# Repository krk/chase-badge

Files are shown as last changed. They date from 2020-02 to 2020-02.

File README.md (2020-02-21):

# chase-badge

Designed using [KiCad](https://kicad-pcb.org/).

I tried to follow datasheet recommendations and tried to base the design on application note schematics and PCB layouts of the active components.

First revision of the board in the repo is rev-8. Earlier revisions are not available in this repo.

Schematics contain notes and all components should have their datasheet in their details in KiCAD.

### Kudos

- to [@smcatala](https://github.com/smcatala) for reviewing the designs!

### Connectors

1. USB-C for power, charging and with bootloader programming.
2. FPC 4-pin for add-on boards.
3. Li-Po JST-SH 2-pin.

### Used ICs

##### ATTINY85V-20SU

- Chosen over ATTINY85V-10SU so we may support [bit-banged USB protocol](https://www.obdev.at/products/vusb/index.html) for programming the badge only with a USB cable. [datasheet](http://ww1.microchip.com/downloads/en/DeviceDoc/atmel-2586-avr-8-bit-microcontroller-attiny25-attiny45-attiny85_datasheet.pdf).

##### TLC6C9512PWR shift register

Chosen for low power consumption and low parts count. [datasheet](http://www.ti.com/lit/ds/symlink/tlc6c5912.pdf).

#### TPS63000 buck-boost regulator

[datasheet](http://www.ti.com/lit/ds/symlink/tps63000.pdf)

#### MCP73837-FCI_UN battery charge manager

[datasheet](http://ww1.microchip.com/downloads/en/DeviceDoc/20002071C.pdf)

### Tested

- Programming ATtiny85 with [Tiny AVR Programmer](https://www.sparkfun.com/products/11801)
- ATtiny85, TLC6C9512 and LEDs can work as expected when powered externally
- 3.3V or 5V is supported.

### Untested

- Power regulator
- Battery charge manager
- XSIG1 external signal, for supporting a buzzer, microphone etc.
- USB bootloader and programming from USB cable.

### TODO

1. Test everything under "untested" above.
2. Determine Li-Po battery size.

### PCB renders of rev-8

Note that some footprints are missing from the renders.

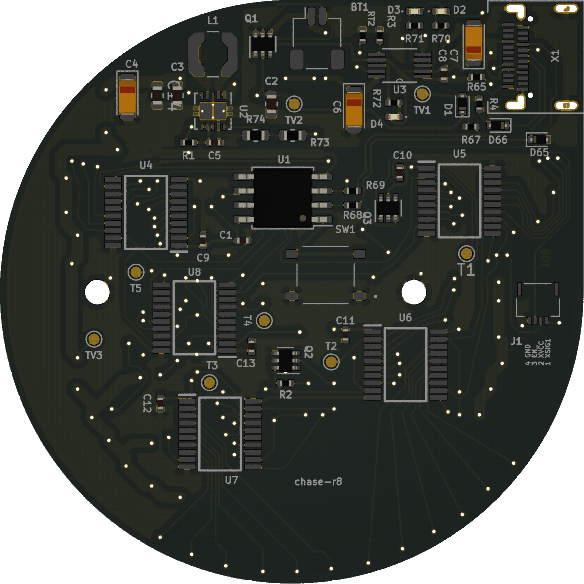
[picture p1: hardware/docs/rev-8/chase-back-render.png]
back


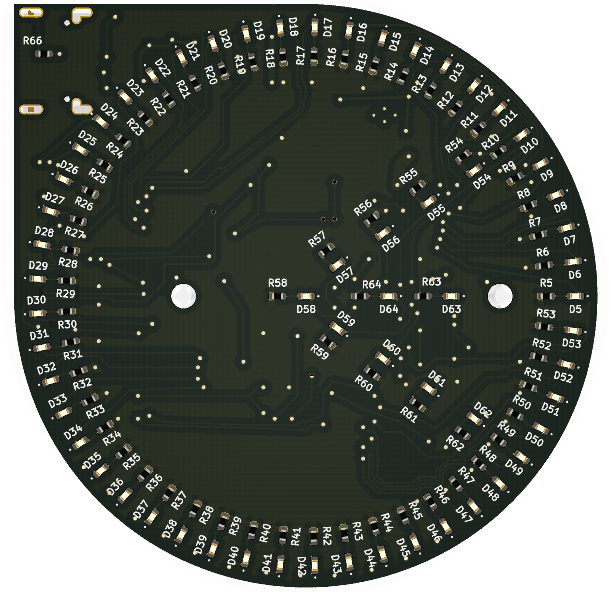
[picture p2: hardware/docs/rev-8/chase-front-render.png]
front


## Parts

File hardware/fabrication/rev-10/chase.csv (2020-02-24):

Part/Designator | Manufacture Part Number/Seeed SKU | Quantity
R1 | 0402WGF1000TCE | 1
R3 | 0402WGF1001TCE | 1
R4 | 0402WGF1003TCE | 1
R2,R5,R6,R7,R8,R9,R10,R11,R12,R13,R14,R15,R16,R17,R18,R19,R20,R21,R22,R23,R24,R25,R26,R27,R28,R29,R30,R31,R32,R33,R34,R35,R36,R37,R38,R39,R40,R41,R42,R43,R44,R45,R46,R47,R48,R49,R50,R51,R52,R53,R54,R55,R56,R57,R58,R59,R60,R61,R62,R63,R64,R70,R71,R72 | 0402WGF4300TCE | 64
R65,R66 | 0402WGF5101TCE | 2
R68,R69 | 0402WGF715JTCE | 2
X1 | 12401610E4#2A | 1
U1 | ATTINY85V-20SU | 1
C1,C5,C8,C9,C10,C11,C12,C13 | CL05B104KO5NNNC | 8
Q1 | DMC3400SDW-7 | 1
Q2,Q3 | DMN61D9UDW | 2
D2,D3,D4,D5,D6,D7,D8,D9,D10,D11,D12,D13,D14,D15,D16,D17,D18,D19,D20,D21,D22,D23,D24,D25,D26,D27,D28,D29,D30,D31,D32,D33,D34,D35,D36,D37,D38,D39,D40,D41,D42,D43,D44,D45,D46,D47,D48,D49,D50,D51,D52,D53,D54,D55,D56,D57,D58,D59,D60,D61,D62,D63,D64 | FC-F1005HOK-600H5 | 63
J1 | FH12-6S-0.5SH(55) | 1
C2,C3,C14 | GRM188Z71A106MA73D | 3
D65,D66 | LM5Z3V6T1G | 2
L1 | LPS4018-222MR_ | 1
U3 | MCP73837-FCI_UN | 1
D1 | NSVR0320MW2T1G | 1
RT2 | NTCG103JF103FT1 | 1
BT1 | SM02B-SRSS-TB(LF)(SN) | 1
R67 | TC0225F1501TCE | 1
C4,C6,C7 | TC212A476K010Y | 3
U4,U5,U6,U7,U8 | TLC6C5912GQPWRQ1 | 5
U2 | TPS63000DRCR | 1
SW1 | TS-1187A-B-A-B | 1

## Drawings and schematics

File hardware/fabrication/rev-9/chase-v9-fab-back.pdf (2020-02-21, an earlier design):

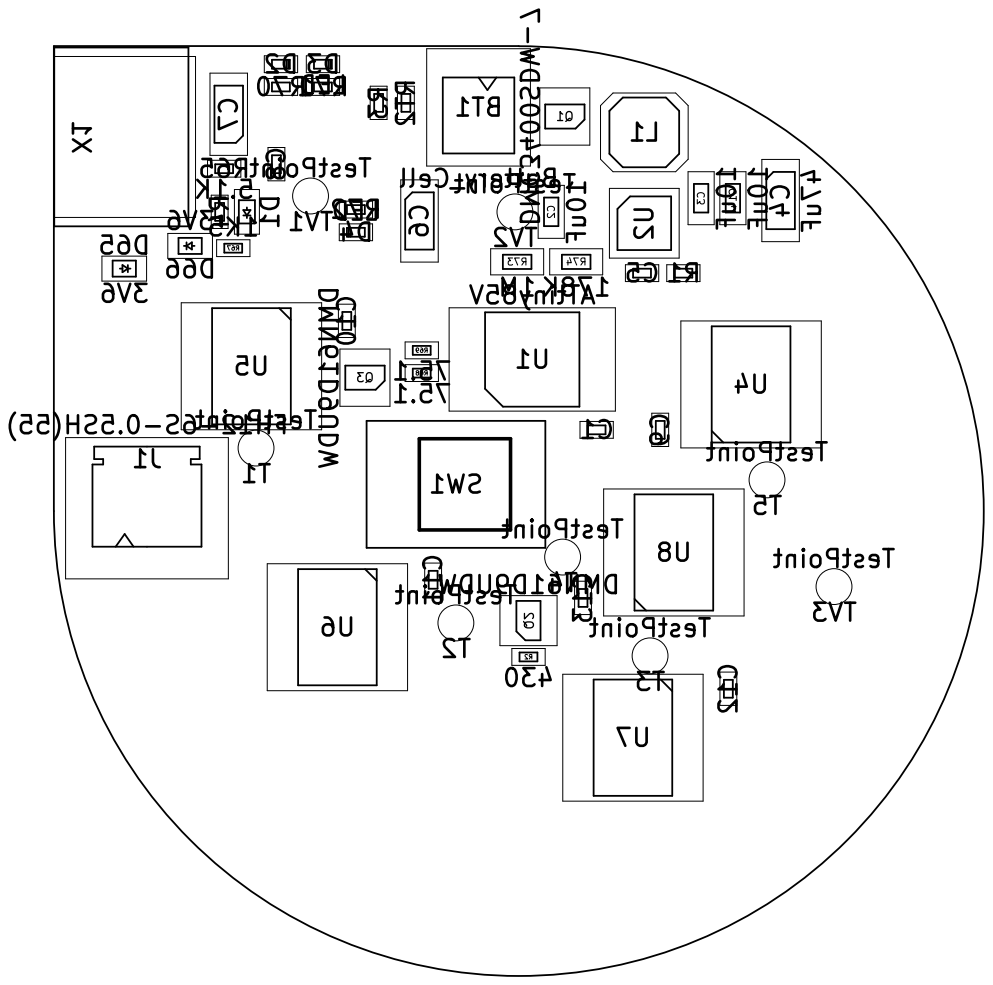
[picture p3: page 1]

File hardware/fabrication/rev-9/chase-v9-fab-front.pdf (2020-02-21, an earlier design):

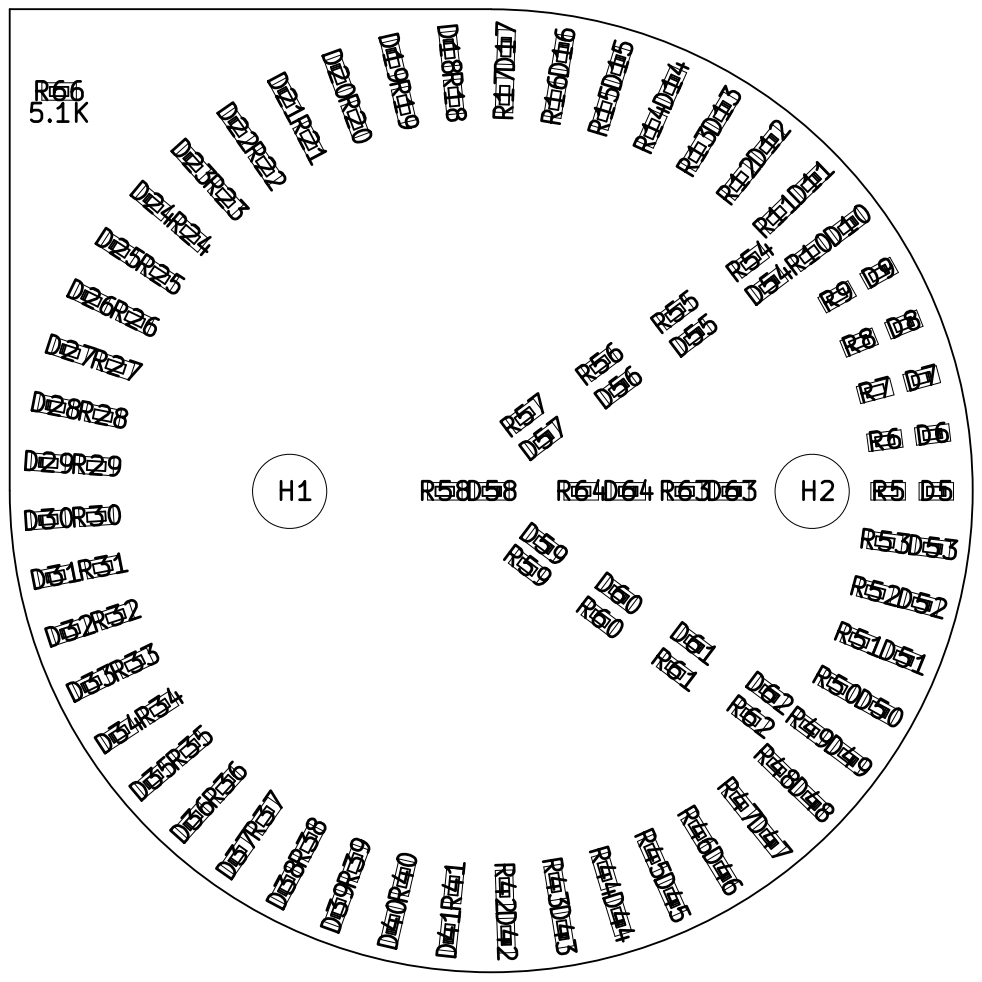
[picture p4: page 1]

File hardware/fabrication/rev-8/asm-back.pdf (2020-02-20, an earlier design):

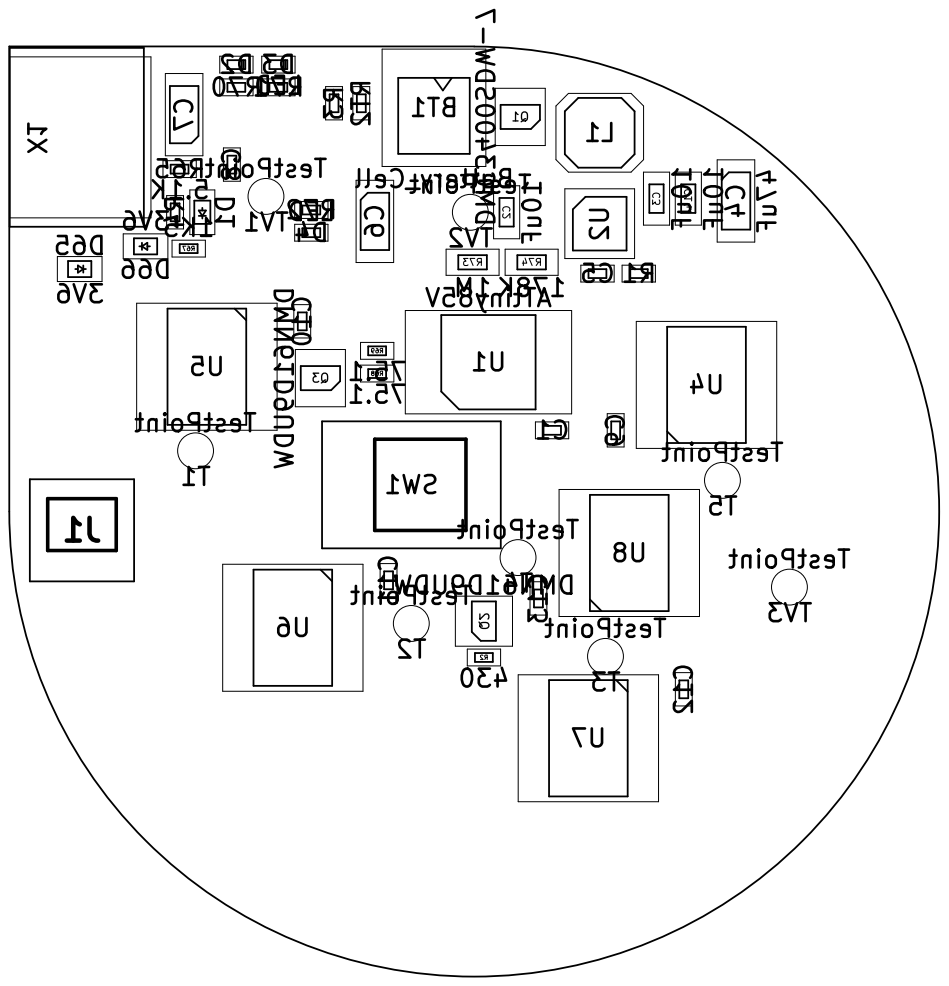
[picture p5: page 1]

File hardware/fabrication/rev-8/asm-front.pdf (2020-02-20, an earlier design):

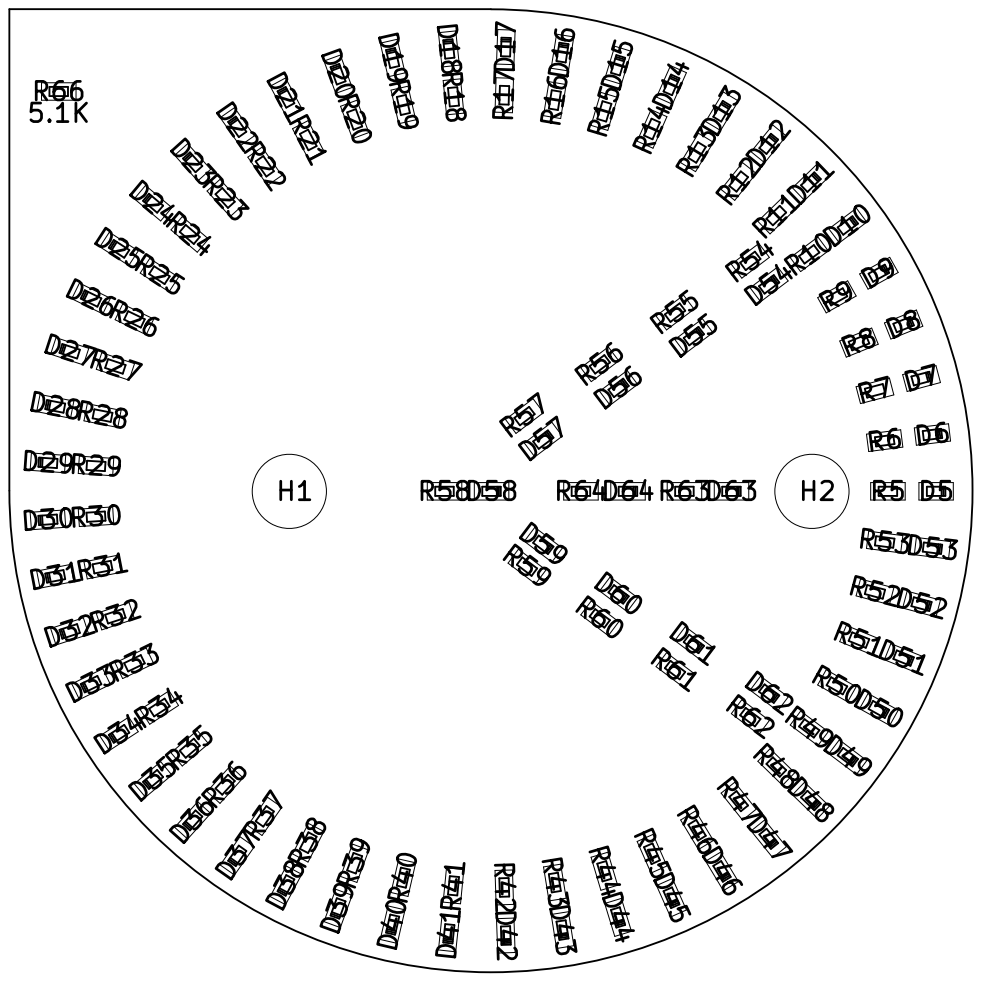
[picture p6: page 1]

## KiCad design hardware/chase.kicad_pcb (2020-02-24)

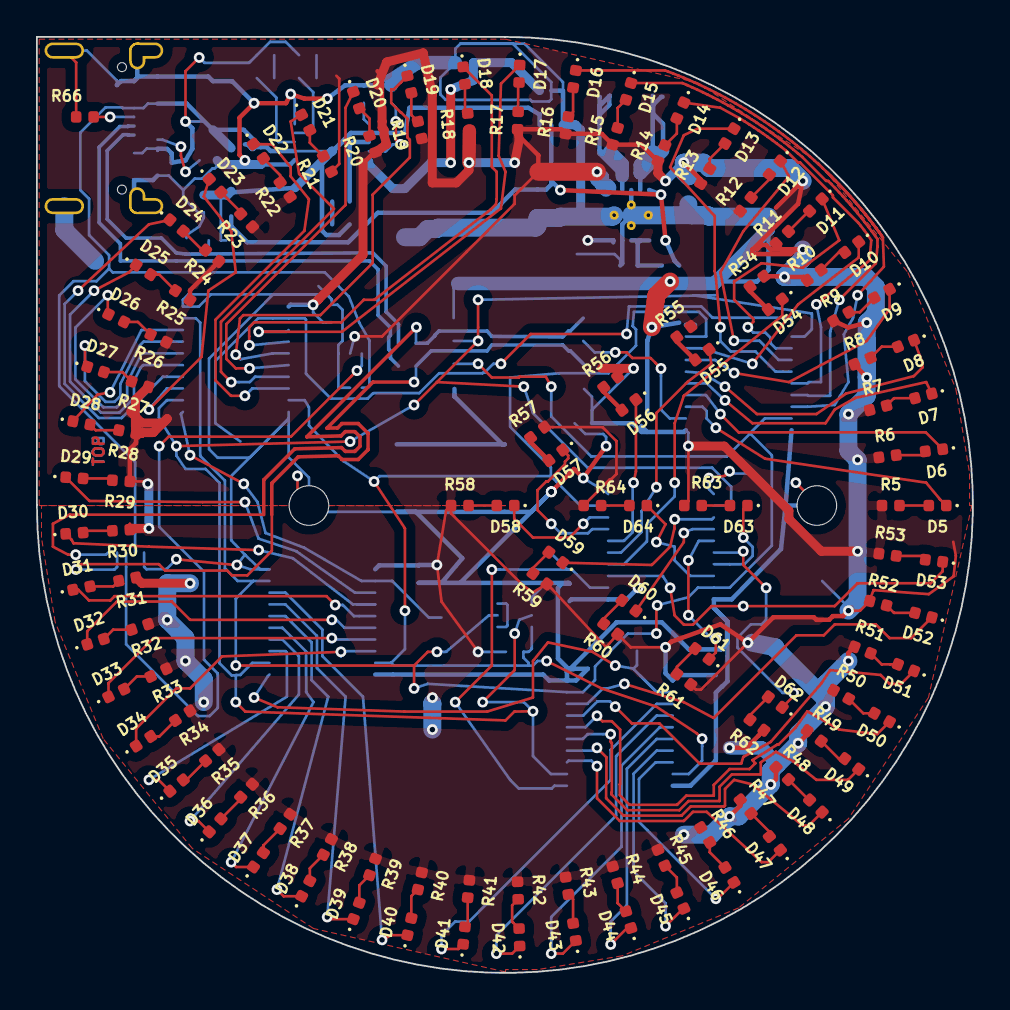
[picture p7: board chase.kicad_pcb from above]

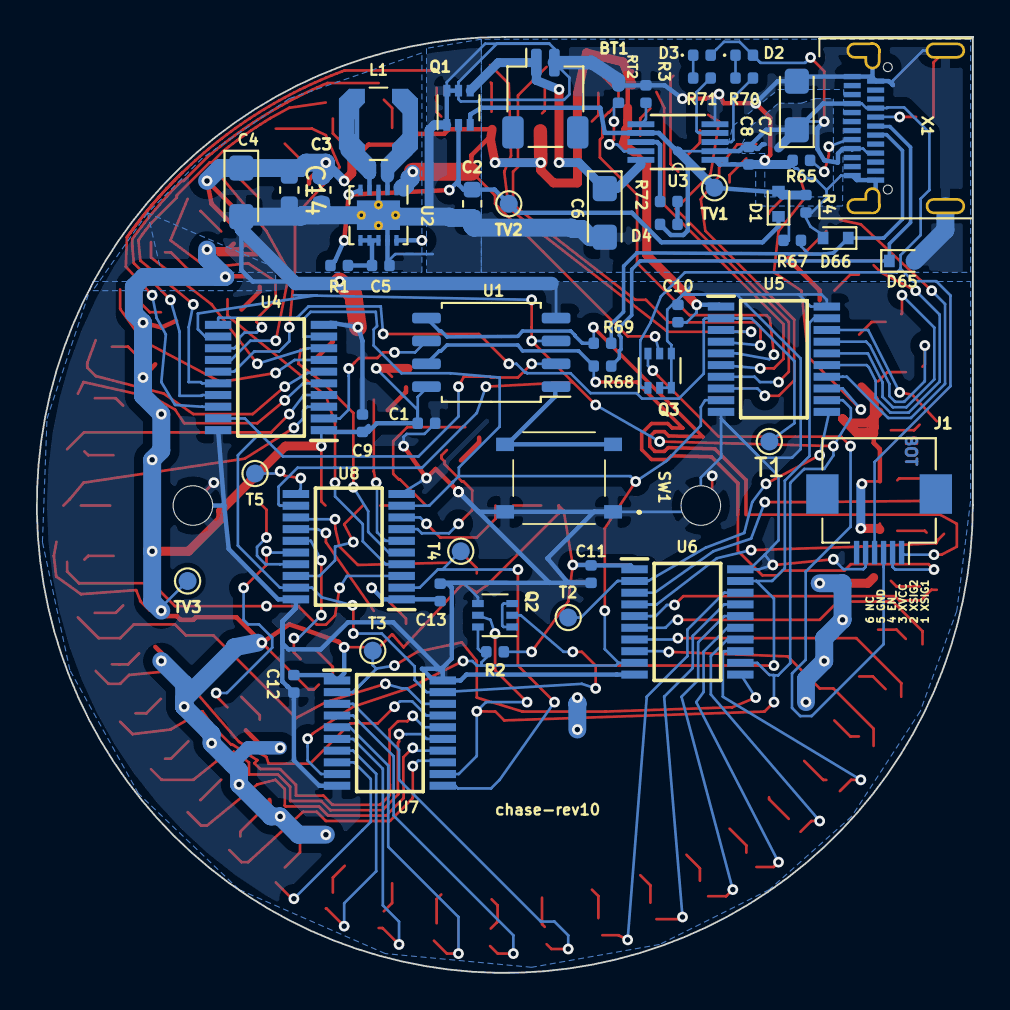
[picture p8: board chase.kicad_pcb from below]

Board: 2 copper layers, 52.0 x 52.0 mm, 179 parts (56 on the bottom side), 154 nets.

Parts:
BT1: Battery_Cell; JST_SH_SM02B-SRSS-TB_1x02-1MP_P1.00mm_Horizontal
C1, C5, C8, C9, C10, C11, C12, C13: 100n; C_0402_1005Metric
C2, C3, C14: 10uF; C_0603_1608Metric
C4, C6, C7: 47uF; CP_EIA-3216-18_Kemet-A
D1: D; D_SOD-523
D2, D3, D4, D5, D6, D7, D8, D9, D10, D11, D12, D13, D14, D15, D16, D17, D18, D19, D20, D21, D22, D23, D24, D25, D26, D27, D28, D29, D30, D31, D32, D33, D34, D35, D36, D37, D38, D39, D40, D41, D42, D43, D44, D45, D46, D47, D48, D49, D50, D51, D52, D53, D54, D55, D56, D57, D58, D59, D60, D61, D62, D63, D64: LED; LED_0402_1005Metric
D65, D66: 3V6; D_SOD-523
H1, H2: MountingHole_Pad; MountingHole_2.2mm_M2_ISO7380
J1: FH12-6S-0.5SH(55); Hirose_FH12-6S-0.5SH_1x06-1MP_P0.50mm_Horizontal
L1: 2.2uH; L_Coilcraft_LPS4018
Q1: DMC3400SDW-7; SOT-363_SC-70-6
Q2, Q3: DMN61D9UDW; SOT-363_SC-70-6
R1: 100; R_0402_1005Metric
R2, R5, R6, R7, R8, R9, R10, R11, R12, R13, R14, R15, R16, R17, R18, R19, R20, R21, R22, R23, R24, R25, R26, R27, R28, R29, R30, R31, R32, R33, R34, R35, R36, R37, R38, R39, R40, R41, R42, R43, R44, R45, R46, R47, R48, R49, R50, R51, R52, R53, R54, R55, R56, R57, R58, R59, R60, R61, R62, R63, R64, R70, R71, R72: 430; R_0402_1005Metric
R3: 1K; R_0402_1005Metric
R4: 100K; R_0402_1005Metric
R65, R66: 5.1K; R_0402_1005Metric
R67: 1K5; R_0402_1005Metric
R68, R69: 75.1; R_0402_1005Metric
RT2: 10K; R_0402_1005Metric
SW1: TS-1187A-B-A-B; TS1187ABAB
T1, T2, T3, T4, T5: TestPoint; TestPoint_Pad_D1.0mm
TV1, TV2, TV3: TestPoint; TestPoint_Pad_D1.0mm
U1: ATtiny85V; SOIC-8_5.275x5.275mm_P1.27mm
U2: TPS63000; Texas_DRC0010J_ThermalVias
U3: MCP73837-FCI_UN; SOP50P490X110-8N
U4, U5, U6, U7, U8: TLC6C5912GQPWRQ1; SOP65P640X120-20N
X1: USB3.1_TYPEC; Type-C_3.1_24P

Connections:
/LED Driver 1/RCK: Q2.5, U1.3, U4.12, U5.12, U6.12, U7.12, U8.12
/LED Driver 1/SER_IN: U1.6, U4.2
/LED Driver 1/SRCK: Q2.2, U1.2, U4.19, U5.19, U6.19, U7.19, U8.19
/LED Driver 1/~CLR: Q2.6, R2.1, U4.9, U5.9, U6.9, U7.9, U8.9
/LED Driver 2/SER_IN: T1.1, U4.11, U5.2
/LED Driver 3/SER_IN: T2.1, U5.11, U6.2
/LED Driver 4/SER_IN: T3.1, U6.11, U7.2
/LED Driver 5/SER_IN: T4.1, U7.11, U8.2
/LED Driver 5/SER_OUT: T5.1, U8.11
/USBD+: D65.1, R68.2, X1.B6
/USBD-: D66.1, R67.1, R69.2, X1.B7
D+: J1.2, R68.1, U1.7
D-: J1.1, R69.1, U1.5
GND: BT1.2, C1.2, C2.2, C3.2, C4.2, C5.1, C6.2, C7.2, C8.1, C9.1, C10.1, C11.1, C12.1, C13.1, C14.2, D65.2, D66.2, H1.1, H2.1, J1.5, Q1.1, Q1.5, Q1.6, Q2.4, Q3.2, Q3.3, Q3.4, R3.2, R4.1, R65.1, R66.1, RT2.1, SW1.A1, SW1.B1, U1.4, U2.3, U2.9, U2.11, U3.1, U3.5, U4.10, U4.20, U5.10, U5.20, U6.10, U6.20, U7.10, U7.20, U8.10, U8.20, X1.A1, X1.A12, X1.B1, X1.B12, X1.SHELL
unnamed: BT1.1, C6.1, Q1.4, U3.10
unnamed: C5.2, R1.1, U2.6, U2.7, U2.8
unnamed: D2.1, R70.2
unnamed: D3.1, R71.2
unnamed: D4.1, R72.2
unnamed: D5.1, U4.3
unnamed: D5.2, R5.2
unnamed: D6.1, U4.4
unnamed: D6.2, R6.2
unnamed: D7.1, U4.5
unnamed: D7.2, R7.2
unnamed: D8.1, U4.6
unnamed: D8.2, R8.2
unnamed: D9.1, U4.7
unnamed: D9.2, R9.2
unnamed: D10.1, U4.8
unnamed: D10.2, R10.2
unnamed: D11.1, U4.13
unnamed: D11.2, R11.2
unnamed: D12.1, U4.14
unnamed: D12.2, R12.2
unnamed: D13.1, U4.15
unnamed: D13.2, R13.2
unnamed: D14.1, U4.16
unnamed: D14.2, R14.2
unnamed: D15.1, U4.17
unnamed: D15.2, R15.2
unnamed: D16.1, U4.18
unnamed: D16.2, R16.2
unnamed: D17.1, U5.3
unnamed: D17.2, R17.2
unnamed: D18.1, U5.4
unnamed: D18.2, R18.2
unnamed: D19.1, U5.5
unnamed: D19.2, R19.2
unnamed: D20.1, U5.6
unnamed: D20.2, R20.2
unnamed: D21.1, U5.7
unnamed: D21.2, R21.2
unnamed: D22.1, U5.8
unnamed: D22.2, R22.2
unnamed: D23.1, U5.13
unnamed: D23.2, R23.2
unnamed: D24.1, U5.14
unnamed: D24.2, R24.2
unnamed: D25.1, U5.15
unnamed: D25.2, R25.2
unnamed: D26.1, U5.16
unnamed: D26.2, R26.2
unnamed: D27.1, U5.17
unnamed: D27.2, R27.2
unnamed: D28.1, U5.18
unnamed: D28.2, R28.2
unnamed: D29.1, U6.3
unnamed: D29.2, R29.2
unnamed: D30.1, U6.4
unnamed: D30.2, R30.2
unnamed: D31.1, U6.5
unnamed: D31.2, R31.2
unnamed: D32.1, U6.6
unnamed: D32.2, R32.2
unnamed: D33.1, U6.7
unnamed: D33.2, R33.2
unnamed: D34.1, U6.8
unnamed: D34.2, R34.2
unnamed: D35.1, U6.13
unnamed: D35.2, R35.2
unnamed: D36.1, U6.14
unnamed: D36.2, R36.2
unnamed: D37.1, U6.15
unnamed: D37.2, R37.2
unnamed: D38.1, U6.16
unnamed: D38.2, R38.2
unnamed: D39.1, U6.17
unnamed: D39.2, R39.2
unnamed: D40.1, U6.18
unnamed: D40.2, R40.2
unnamed: D41.1, U7.3
unnamed: D41.2, R41.2
unnamed: D42.1, U7.4
unnamed: D42.2, R42.2
unnamed: D43.1, U7.5
unnamed: D43.2, R43.2
unnamed: D44.1, U7.6
unnamed: D44.2, R44.2
unnamed: D45.1, U7.7
unnamed: D45.2, R45.2
unnamed: D46.1, U7.8
unnamed: D46.2, R46.2
unnamed: D47.1, U7.13
unnamed: D47.2, R47.2
unnamed: D48.1, U7.14
unnamed: D48.2, R48.2
unnamed: D49.1, U7.15
unnamed: D49.2, R49.2
unnamed: D50.1, U7.16
unnamed: D50.2, R50.2
unnamed: D51.1, U7.17
unnamed: D51.2, R51.2
unnamed: D52.1, U7.18
unnamed: D52.2, R52.2
unnamed: D53.1, U8.3
unnamed: D53.2, R53.2
unnamed: D54.1, U8.4
unnamed: D54.2, R54.2
unnamed: D55.1, U8.5
unnamed: D55.2, R55.2
unnamed: D56.1, U8.6
unnamed: D56.2, R56.2
unnamed: D57.1, U8.7
unnamed: D57.2, R57.2
unnamed: D58.1, U8.8
unnamed: D58.2, R58.2
unnamed: D59.1, U8.13
unnamed: D59.2, R59.2
unnamed: D60.1, U8.14
unnamed: D60.2, R60.2
unnamed: D61.1, U8.15
unnamed: D61.2, R61.2
unnamed: D62.1, U8.16
unnamed: D62.2, R62.2
unnamed: D63.1, U8.17
unnamed: D63.2, R63.2
unnamed: D64.1, U8.18
unnamed: D64.2, R64.2
unnamed: L1.1, U2.4
unnamed: L1.2, U2.2
unnamed: Q2.1, Q2.3
unnamed: R3.1, U3.6
unnamed: R65.2, X1.A5
unnamed: R66.2, X1.B5
unnamed: R70.1, U3.3
unnamed: R71.1, U3.4
unnamed: R72.1, U3.8
unnamed: RT2.2, U3.9
unnamed: SW1.C1, SW1.D1, U1.1
VBATOUT: C2.1, D1.1, Q1.2, R1.2, TV2.1, U2.5
VBUS: C7.1, C8.2, D1.2, D2.2, D3.2, D4.2, J1.4, Q1.3, Q3.1, R4.2, R67.2, TV1.1, U3.2, U3.7, X1.A4, X1.A9, X1.B4, X1.B9
VCC: C1.1, C3.1, C4.1, C9.2, C10.2, C11.2, C12.2, C13.2, C14.1, Q3.5, R2.2, R5.1, R6.1, R7.1, R8.1, R9.1, R10.1, R11.1, R12.1, R13.1, R14.1, R15.1, R16.1, R17.1, R18.1, R19.1, R20.1, R21.1, R22.1, R23.1, R24.1, R25.1, R26.1, R27.1, R28.1, R29.1, R30.1, R31.1, R32.1, R33.1, R34.1, R35.1, R36.1, R37.1, R38.1, R39.1, R40.1, R41.1, R42.1, R43.1, R44.1, R45.1, R46.1, R47.1, R48.1, R49.1, R50.1, R51.1, R52.1, R53.1, R54.1, R55.1, R56.1, R57.1, R58.1, R59.1, R60.1, R61.1, R62.1, R63.1, R64.1, TV3.1, U1.8, U2.1, U2.10, U4.1, U5.1, U6.1, U7.1, U8.1
XVCC: J1.3, Q3.6

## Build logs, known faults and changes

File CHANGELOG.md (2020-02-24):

### hardware rev10:

- Use cheaper 0402WGF715JTCE instead of ARG02FTC71R5 for 71.5 ohm resistors.
- Use TPS63001, which is in stock, instead of TPS63000 to reduce parts count by removing R73 and R74.

### hardware rev9:

- J1 4-pin FPC connector not in stock, replaced with 6 pin.
- Moved USB signals to PB0 and PB2, exposed both on J1. With these pins, add-on boards can optionally use I2C.
- Use cheaper 0402WGF4300TCE instead of ARG02FTC4300 for 430 ohm resistors.

### hardware rev8:

- Initial import.

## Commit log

2020-02-20 Import chase-v8.
    [chase-B_Cu.gbr, chase-B_Mask.gbr, chase-B_Paste.gbr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]
2020-02-21 Replace J1 with 6 pin connector, use cheaper resistor for 430 ohms.
    [chase-B_Cu.gbr, chase-B_Mask.gbr, chase-B_Paste.gbr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]
2020-02-24 Change TPS63000 variable to TPS63001 3.3V buck-boost.
    TPS630001 is in stock now, can use it again. R73 and R74 are not
    necessary now.
    Change resistor brand for 71.5ohm resistors.
    From VikingTech to UniRoyal which is cheaper.
    [chase-B_Cu.gbr, chase-B_Mask.gbr, chase-B_Paste.gbr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]
2020-02-24 Add fabrication BOM files.
    [chase.csv]
